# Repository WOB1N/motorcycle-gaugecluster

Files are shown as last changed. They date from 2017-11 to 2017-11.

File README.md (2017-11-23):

# SV650 Digital Gauges

## Project description
This repo contains all resources that I've used to make a gauge cluster for a first generation Suzuki SV650 (1999-2002). Everything from wiring loom schematics, diagrams of my custom arduino "shield", the software that I run on it, the components and connectors that I've used, bitmap-icons, 3D-models of the case (for 3D-printing), etc. Basically all information that might be useful to others in some way.

For recent changes and current status of the project, please check out [this changelog](CHANGELOG.md). Alternatively, if you'd like to know more about the used components, have a look at [this page](COMPONENTS.md).

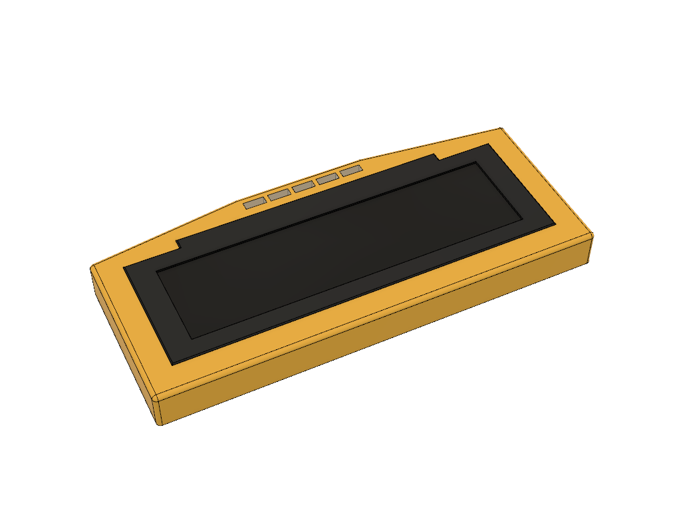
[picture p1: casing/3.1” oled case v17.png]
display in case


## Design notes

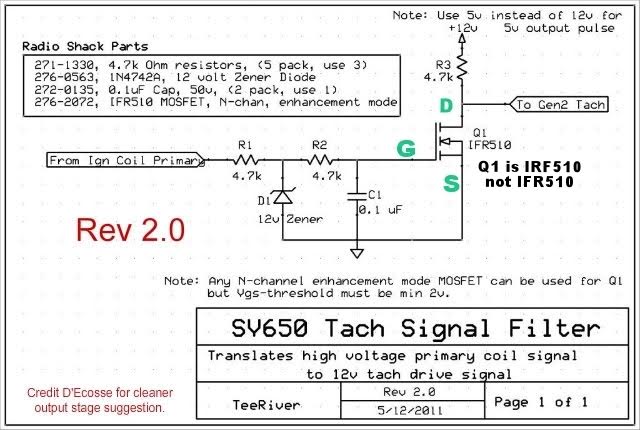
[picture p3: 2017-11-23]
documentation/decosse_tacho_filter_schematic.jpg

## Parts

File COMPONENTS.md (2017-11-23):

# Component list

## Display

The display was a hard choice. I wanted something that was not too expensive, easily readable in direct sunlight, with a reasonable resolution. Also, it needs to have a decent refresh-rate so there won't be noticable lag in speed and rpm numbers. If you're looking for the cheapest option; don't buy the slightly cheaper 3.3v version as it isn't compatible with the 5v ATMega I/O-pins

| Specs 		|				 |
| --- | --- |
|Brand			| East Rising	 |
|Type			| 3.2" OLED		 |
|Resolution 	| 256x64 		 |
| Colors 		| 4bit grayscale |
|Logic level 	| 5v 			 | 
|Interface 		| 4 wire SPI 	 |
|Controller  	| SSD1322 		 |

*Alternatives:* I've also seriously considered the iTead Nextion and NewHaven 4.3" TFT touch panels. The former can only be programmed with and IDE that requires Windows and the latter was very expensive. I didn't require a touchpanel because it wouldn't work with gloves anyway, so I went with the OLED option.

display pic

## Connectors

I didn't want to cut the wiring loom on the motorcycle, so I've sourced the original connectors (or at least ones that are compatible). These are, however, not so easy to find online. But eventually I found them. They can be ordered through AliExpress, EasternBeaver and CycleTerminal. You will need both the 6-pin and 10-pin connectors. And if you buy from a Chinese store: often the pins are sold separately..

| Connector | Brand			| Model 	|
| --- | --- | --- |
| 6-pin  	| Sumitomo  	| HM 090	|
| 10-pin  	| Sumitomo  	| MT 090 	|

*Alternatives:* Just remove the old connectors from the motorcycle, and replace them with molex-connectors. Just as good, but easier to come by and also cheaper. 

10 pin connector

## Power supply (DC-DC step down converter)

This unit is not cheap compared to a linear voltage regulator (for example an LM7805). It can be bought at any local radioshack for about eight euros. But it doesn't get hot, it takes any input up to 32v, it can deliver up to 1Amp, and it's relatively insensitive to voltage spikes. Also, it has a reasonably small form-factor. 

| Specs 			| 														|
| --- | --- |
| Brand				| TracoPower											|
| Type				| TSR-1 2450 											|
| Input voltage 	| up to 32v 											|
| Output voltage 	| 5v													|
| Datasheet 		| [link](https://www.tracopower.com/products/tsrn1.pdf) |

Alternatives: I believe an LM7805 with heatsink would work fine as well, considering the fact that this OLED-screen doesn't consume much power at all. But if you (like me) would like to coat the PCBs in some kind of epoxy for water-resistance, then heatsinks are a no-go.

traco power supply

## Microcontrollers

The microcontroller will need to monitor speed and engine rpm continuously while also updating a display with a decent refresh rate. To prevent flickering the display-loop must not be interrupted. But at the same time, the sensor-interrupts may not be ignored for this will cause inaccuracies. So I decided to go with 2 microprocessors. A dedicated "core" for each task. 

Also, I'd like to use Arduino's, mainly because of the wide variety of available examples, tutorials and FAQs. But I don't like these huge proto-boards, so I decided to go for a minimal setup. I picked an ATMega328 as "main" processor, with plenty of pins for connecting a display and some other inputs. And a cute little ATTiny85 for counting pulses from the sparkplug and wheel-rotation sensor.

| Processor  | Datasheet | 
| --- | --- |
| ATMega328p | [link](http://www.atmel.com/Images/Atmel-42735-8-bit-AVR-Microcontroller-ATmega328-328P_Datasheet.pdf) |
| ATTiny85 | [link](http://www.atmel.com/images/atmel-2586-avr-8-bit-microcontroller-attiny25-attiny45-attiny85_datasheet.pdf) |

*Alternatives:* If you're willing to spend a bit more money, you might want to go with a faster, single processing unit. Especially if you want to connect more sensors or need to push more pixels to a bigger (full color?) display. I can personally recommend a Teensy 3.x for this purpose. It's 32bit 180MHz core is brutally fast, but beware: is has 3.3v I/O-pins so make sure this is compatible with the display you're using.

atmega328

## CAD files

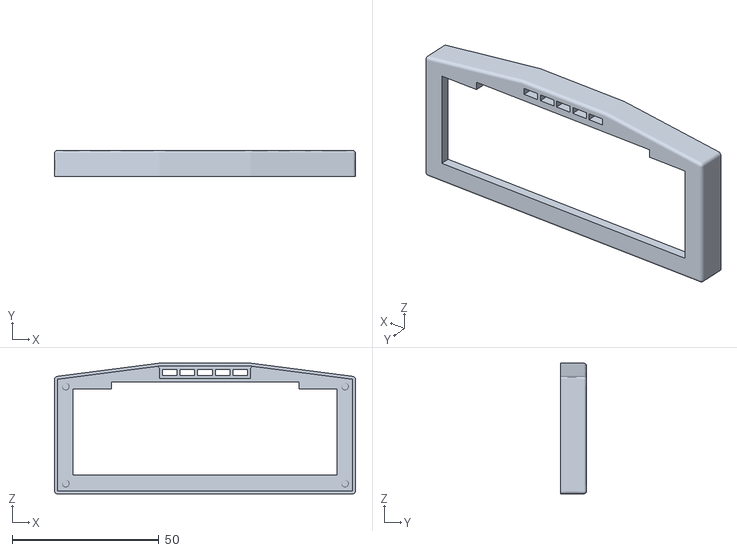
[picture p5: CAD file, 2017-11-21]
casing/3_1_oled_case.stl
102.7 x 9.00 x 44.6

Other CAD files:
casing/3.1” oled case v17.f3d

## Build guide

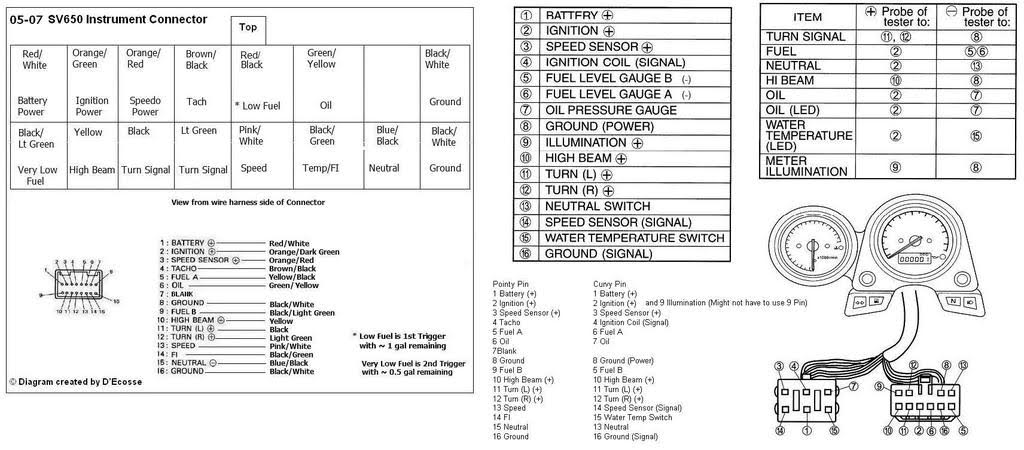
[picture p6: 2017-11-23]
documentation/pinout_wiring_loom.jpg

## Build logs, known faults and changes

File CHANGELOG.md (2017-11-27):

## Current status / changelog

### 25-11-2017:
Since my barebone ATMega328p does not support console output, I bought a cheap SPI TFT-display merely for testing. Tested the protoboard with the display; it worked fine, pretty neat. Then I tested the whole setup standalone on the motorcycle. Got some not-so-great results. Tacho was working. Speedo was not. According to [this video](https://www.youtube.com/watch?v=H7d9fukFccY) the sensor should output 5v when the magnet passes. But thats a 2002+ second generation SV650. Turns out that my older style "sensor" connects signal to ground when the magnet passes. So I re-soldered that part of the proto-board and updated the Fritzing file accordingly. At this point, the display just displays two numbers. No graphics of any kind. But it's working.

What I realized while watching the numbers in front of me, is that counting sensor-pulses in the last 500ms is not a very accurate measurement at all. Since the rpm-signal will trigger once at every revolution, it will -at idle- count about 1500rpm/60sec=25 pulses per second. Or 12.5 pulses per 500ms. This seemed reasonable at first, until I realized that it also means that every single pulse per 500ms accounts for 120rpm. I'm not sure if I like these 120rpm increments. A more precise measurement for low rpm might be to count the nanoseconds between pulses. At 1500rpm, there would be about 400ns beween pulses. However, at 10500rpm this interval would be reduced to about 50ns. Considering that the internal clock may be 4ns off at any time.. this would lead to a 4/50x100=8% inaccuracy at maximum engine speed. Hmmph. 

I'll keep it simple for now, until there is a clear reason why 120rpm increments suck.

progress pic progress so far

### 21-11-2017: 
Sent the model to the 3D-hub. Also, still waiting for the display to arrive. 

### 19-11-2017: 
Found a sheet containing dimensions of my OLED-display. So I've downloaded the trail version of Fusion360 and started mocking up a crude (but correctly sized) model of the display. Also tried to model some sort of a casing, but its ugly. Very. Ugly. But I want to just 3D-print anything simply to get a feel for the quality of the resulting object. And also what tolerances I need to use / accuracy issues I need to deal with. Used 3D-hubs to find a hub that will print for a reasonable price. 

### 17-11-2017: 
Still waiting for the bloody display to arrive. I'm already fantasizing about what I will do with all those sixteen-thousand-threehundred-and-eightyfour pixels. I felt inspired and downloaded GIMP. Created some tiny, very pixelated, 16x16 icons. Hope they will be readable on the screen. I've [exported the icons to byte-arrays in c-sourcecode format](https://github.com/RobinWagenaar/motorcycle-gaugecluster/tree/master/software/graphics). Did I mention that GIMP rocks? No? Gimp rocks. And U8GLIB has this neat function called drawXBMP(..). Which, theoretically, should be able to draw these byte-arrays. Fingers crossed.

icon set

I'm wondering... I will connect the display via SPI, which saves I/O-pins compared to the 8-bit parallel interface but is probably also a fair bit slower. Therefore, reducing the number of commands sent to the display may be a way to compensate for this. Since I suspect that drawXBMP(..) will simply loop through all pixels in the image and draw them separately. But decomposing these simple images into rectangles and lines would result in less commands. Which might be a lot faster. On second thought, the refesh-rate/speed matters primarily on the stats that change often, like speed and rpm. Hmm.. food for thought.

### 16-11-2017: 
I bought a neat little switched power supply from Traco, which accepts voltages up to 40v and outputs a very steady 4.99v. Will add in part numbers later.

### 15-11-2017: 
Soldered a ATMega328P to my proto-board. Hooked up I2C as well as some other signal wires. Decided that I trust these signals a little bit more than the dreaded spark plug signal, so I won't be using opto-couplers to shield the I/O pins on these lines. Insead went with 47k/100k voltage-dividers to turn down the voltage from 12-15v to a more acceptable 4-5v.

### 12-11-2017: 
Pondered about all functions that these gauges must have. Turn indicators, neutral light, high beam indicator, water/oil warning,  speedo, tacho, distance, and then there are these darned thermistor fuel sensors which I don't quite understand yet. Tried to coun the number of I/O-pins that would be needed. Took into account that some pins are needed for communication and the external crystal. Finally came to the conclusion this must be doable with a regular ATMega328 as main processing unit. 

### 11-11-2017: 
Decided that waiting for my OLED-display is boring, so I've hooked up an I2C-connection from the ATTiny85 to another UNO. Made the painful mistake of miswiring the required pullup resistors as pulldown-resistors. Sadly it took a while before I found the culprit, but I2C is now operational. Used the TinyWire library to make the ATTiny a slave device with address #3. Three, because, reasons.

### 10-11-2017: 
Decided that using two LEDs as a debugger is stupid. Also, my girlfriend thinks I'm crazy for staring into flickering LEDs for hours. So I've ordered a monochrome graphical OLED-display with 256x64 pixels. These badboys are readable in direct/bright sunlight, not too expensive, can do 4-bit grayscale, and it should be fairly easy for an Arduino to drive the SSD1322 chip over SPI using u8glib.

A company called NewHaven produces the displays. But ofcourse I bought a chinese knockoff. This might bite me later. 

### 06-11-2017: 
Cleaned up the ATTiny software a bit. This ATTiny85 will be counting the number of pulses on the speedo and tacho wires, but must also communicate with a "main" microprocessor every once in a while. Therefore decided to work with interrupts instead of polling for both signal wires.

### 05-11-2017: 
Wrote very crude software for the ATTiny, and programmed it on a breadboard with an Arduino Uno as ISP. It turns on leds when the signals are HIGH. The speedo led is flashing as expected but seems to me as if the tacho wire is normally high and gets pulled down on spark; unexpected but fine. 

### 04-11-2017: 
I've soldered a proto-board containing the tacho filter from D'Ecosse and TeeRiver, and connected it to an ATTiny85. I suspect that the pulses from the coil pack may harm the microcontroller, so for safety reasons I now run the signal through an opto-coupler. Did the same for the speedo signal.

### How it all started:
Ok, so, here is what happened.. A couple of months ago, my girlfriend bought her first motorcycle. A pitch black Suzuki SV650 from 1999. The naked bike of the so called "curvy" -first- generation. She had her mind set on getting this exact motorcycle, and literally scoured online marketplaces for weeks before finding one in good condition. When she finally found one that met her criteria, there was only one issue: she didn't have her license yet. So in the meanwhile, I drove it around. And I quite enjoyed the rides because it's a really easy handling little motorcycle. Unfortunately, not much later, I found out that even easy handling little motorcycles can crash. Hard. 

I will spare you the details of the crash, but as you might imagine, I wasn't too proud of my actions and decided to fix the bike as quickly as humanly possible. With the speed of light, I sourced all the nessesary parts and started the reparations. But fixing up one thing led to another, and another, and before I knew it, this project turned into a full bike rebuild. Lucky for me, this naked bike was easy enough to work on, and it took me less than a month to make the bike look and run like new. Except for one little part, that turns out to be impossibly hard to find. The asymmetric, ugly-as-hell, gauge cluster. 

In fact, I'm still searching eBay and other websites on a daily basis. But as long as I can't find an undamaged unit for a reasonable price, I will try to make my own. Sooo... _hello wiring loom from '99; meet my little friend Arduino over here._

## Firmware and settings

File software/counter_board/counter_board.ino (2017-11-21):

/*
  This ATTiny85 is responsible for counting pulses coming from the speedo- and tacho-
  sensors. These incoming signal frequencies fluctuate between 1-350Hz. This unit has
  three main requirements:

  A) Correct: Meaure the pulses as accurately as possible. This is also partially
     covered by filtering/debouncing hardware).

  B) Up-to-date: Communicate readings that are as recent as possible. For now, 
     this translates to the number of pulses measured in the last 500ms.

  C) Responsive: Respond instantly to I2C requests, so that the master have high
     refresh rates on the display.

  TODO1: Current engine rpm and speed surely are nice, but we also need total distance 
         and trip distance.
  TODO2: And possibly gear position?
*/
#include <TinyWireS.h>

#define I2C_SLAVE_ADDRESS 0x3
#define SPEEDO_SIGNAL PCINT3
#define TACHO_SIGNAL PCINT4
#define BUFFER_SIZE 5
#define LOOP_DELAY 100
#define LED PB1

volatile uint8_t speedo_counter = 0;
volatile uint8_t tacho_counter = 0;

uint8_t cache_index = 0;
uint8_t speedo_buffer[BUFFER_SIZE] = {0, 0, 0, 0, 0};
uint8_t tacho_buffer[BUFFER_SIZE] = {0, 0, 0, 0, 0};

uint16_t SPEEDO_DEBOUNCE_TIME = 500; //us = 0.5 ms
uint16_t TACHO_DEBOUNCE_TIME = 300;  //us = 0.3 ms


void setup() {
  // speedo and tacho signal pins are inputs
  pinMode(SPEEDO_SIGNAL, INPUT);
  pinMode(TACHO_SIGNAL, INPUT);

  // yay a debugging led always comes in handy
  pinMode(LED, OUTPUT);

  // the ATTiny-way to setup interrupts
  GIMSK |= (1 << PCIE);           // pin change interrupt enable
  PCMSK |= (1 << SPEEDO_SIGNAL);  // pin change interrupt enabled for speedoSignal pin
  PCMSK |= (1 << TACHO_SIGNAL);   // pin change interrupt enabled for tachoSignal pin

  // start the i2c slave
  TinyWireS.begin(I2C_SLAVE_ADDRESS);
  TinyWireS.onRequest(incomingI2CRequest);

  // enable interrupts
  sei();
}

/**
  For each sensor, there is a pulse-counter which is incremented by an interrupt-
  service-routine (ISR). There is also a buffer containing measurements. Every 100ms,
  this main loop wakes up and overwrites the oldest value in the buffer with the value
  of the counter. The counter is cleared, and the main loop goes to sleep for another
  100ms.

  The buffer contains 5 'countings' of pulses per 100ms. When the I2C master requests
  data, all values in the buffer are added up which gives us the total number of pulses
  in the last 500ms. But this data is only 100ms old (worst case)

  I have considered simpler approaches, but I believe this is the easiest way to be both
  accurate (long measurement interval) and up-to-date.

  Simply count with interrupts and clear the counters every 500ms: This won't work
  because we never know when the I2C master will request data. It's totally possible
  that we've only been counting for 400ms when the data-request comes in, and then we
  would miss out on the last 100ms (requirement A). In this case we could return the
  last known value of a completed measurement, but this data is 400ms old and this
  would not result in a very responsive display (hence requirement B).

  Decrease measurement interval and extrapolate the counters. Due to the relatively
  low signal frequencies I believe it's not acceptable to decrease the measurement
  interval (to +/-10ms?) and multiply the number of counted pulses (by 50?). I think
  this would result in a very high (multiplied) error ratio (which would clash with
  requirement A).
*/
void loop() {
  tws_delay(LOOP_DELAY);
  speedo_buffer[cache_index] = speedo_counter;
  speedo_counter = 0;
  tacho_buffer[cache_index] = tacho_counter;
  tacho_counter = 0;
  cache_index = (cache_index + 1) % BUFFER_SIZE;
  TinyWireS_stop_check();
}

/**
  ISR routine which does some very crude microsecond-time based debouncing. Notice
  that the debounce on the tacho is "tigher" than on the speedo, since the expected
  signal frequencies on the tacho are a bit higher. Also, this code only increments
  the counters on rising edge (while the routine is called on both rising and falling
  edge).

  NOTE TO SELF1: check if there is an easier way for edge detection? MCUCR?
  NOTE TO SELF2: buy oscilloscope to check if the debouncing actually works.
*/
uint8_t porthistory = 0x00;
ISR(PCINT0_vect) {
  uint32_t current_time = 0;
  uint8_t changedbits = PINB ^ porthistory;
  porthistory = PINB;

  static boolean tacho_toggle = true; // act on rising edge only
  tacho_toggle = !tacho_toggle;
  if (tacho_toggle) {
    current_time = micros(); // very crude debouncing
    if (changedbits & (1 << TACHO_SIGNAL)) {
      static uint32_t last_tacho_interrupt = 0;
      if (current_time - last_tacho_interrupt > TACHO_DEBOUNCE_TIME) {
        tacho_counter++;
      }
      last_tacho_interrupt = current_time;
    }
  }

  static boolean speedo_toggle = true; // act on rising edge only
  speedo_toggle = !speedo_toggle;
  if (speedo_toggle) {
    current_time = micros(); // very crude debouncing
    if (changedbits & (1 << SPEEDO_SIGNAL)) {
      static uint32_t last_speedo_interrupt = 0;
      if (current_time - last_speedo_interrupt > SPEEDO_DEBOUNCE_TIME) {
        speedo_counter++;
      }
      last_speedo_interrupt = current_time;
    }
  }
}

/*
  When the I2C-master requests for data, this function:
  A) Calculates the sum of both buffers (which gives us total pulses over the last 500ms).
      This results in two 16bit integers: totalSpeedo and totalTacho.
  B) Instructs TinyWire to respond with 4 bytes:
     1: Most significant byte of totalSpeedo
     2: Least significant byte of totalSpeedo
     3: Most significant byte of totalTacho
     4: Least significant byte of totalTacho
*/
boolean led_state = LOW;
void incomingI2CRequest() {
  led_state = !led_state;
  digitalWrite(LED, led_state);

  uint16_t totalSpeedo = 0;
  uint16_t totalTacho = 0;
  for (int i = 0; i < BUFFER_SIZE; i++) {
    totalSpeedo += speedo_buffer[i];
    totalTacho += tacho_buffer[i];
  }

  TinyWireS.send(totalSpeedo >> 8);
  TinyWireS.send(totalSpeedo & 0xFF);
  TinyWireS.send(totalTacho >> 8);
  TinyWireS.send(totalTacho & 0xFF);
}

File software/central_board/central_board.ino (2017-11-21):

#include <Wire.h>

#define TURN_LEFT_PIN 0
#define TURN_RIGHT_PIN 1
#define HIGH_BEAM_PIN 2
#define NEUTRAL_PIN 3
#define OIL_WARNING_PIN 4

#define WATER_TEMP_PIN 17
#define FUEL_WARNING_2_PIN  16
#define FUEL_WARNING_1_PIN 15
#define BATTERY_VOLTAGE_PIN 14

volatile uint16_t speedoTicks = 0;
volatile uint16_t tachoTicks = 0;

bool turningLeft = false;
bool turningRight = false;
bool highBeam = false;
bool neutral = false;
bool oilWarning = false;
bool waterTempWarning = false;
bool fuelWarning1 = false;
bool fuelWarning2 = false;

void setup() {
  initializeIndicatorInputs();

  pinMode(A0, OUTPUT);

  Wire.begin();        // join i2c bus (address optional for master)
  Serial.begin(115200);  // start serial for output
}

void loop() {
  readIndicatorInputs();

  // read speedo and tacho
  Wire.requestFrom(3, 4);    // request x bytes from slave device #3
  while (Wire.available()) { // slave may send less than requested
    int a = Wire.read();
    int b = Wire.read();
    int c = Wire.read();
    int d = Wire.read();

    speedoTicks = (a << 8) | b;
    tachoTicks = (c << 8) | d;

    Serial.print(speedoTicks);
    Serial.print("\t");
    Serial.println(tachoTicks);
  }

  delay(100);
}

void initializeIndicatorInputs(){
  pinMode(TURN_LEFT_PIN, INPUT);
  pinMode(TURN_RIGHT_PIN, INPUT);
  pinMode(HIGH_BEAM_PIN, INPUT);
  pinMode(NEUTRAL_PIN, INPUT);
  pinMode(OIL_WARNING_PIN, INPUT);
  pinMode(WATER_TEMP_PIN, INPUT);
  pinMode(FUEL_WARNING_1_PIN, INPUT);
  pinMode(FUEL_WARNING_2_PIN, INPUT);
}

void readIndicatorInputs(){
  turningLeft = digitalRead(TURN_LEFT_PIN);
  turningRight = digitalRead(TURN_RIGHT_PIN);
  highBeam = digitalRead(HIGH_BEAM_PIN);
  neutral = digitalRead(NEUTRAL_PIN);
  oilWarning = digitalRead(OIL_WARNING_PIN);
  waterTempWarning = digitalRead(WATER_TEMP_PIN);
  fuelWarning1 = digitalRead(FUEL_WARNING_1_PIN);
  fuelWarning2 = digitalRead(FUEL_WARNING_2_PIN);
  
  //read analog inputs:
  // - TODO: do something with BATTERY_VOLTAGE_PIN
}

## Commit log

2017-11-21 initial import
    [3.1” oled case v17.f3d, 3_1_oled_case.stl, counter_board.fzz]
2017-11-23 added schematics
2017-11-23 updated attiny85 schematic
2017-11-27 updated schematic for new insights about speedo sensor inner workings
    [counter_board.fzz]
